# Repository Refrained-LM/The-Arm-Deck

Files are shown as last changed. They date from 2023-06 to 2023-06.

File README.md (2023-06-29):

# The-Arm-Deck
A customizable handheld device

First I would Like to name the users that have helped in either their model being used under Creative Commons (Give credit with a link), Stock, or modified to achieve this prototype.

EYEWINK 7" HDMI Display-C Case by ywabiko on Printables: https://www.printables.com/model/85018-eyewink-7-hdmi-display-c-case

Joycon Thumbstick by Keepinitril on Thingiverse: https://www.thingiverse.com/thing:5533819

Potentiometer trigger stackable by lynlim on Thingiverse: https://www.thingiverse.com/thing:1681562

Spring loaded linear converter Potentiometer  by Yoink_0b3 on Thingiverse: https://www.thingiverse.com/thing:2954927

Tactile Push Button(6x6x5mm) Switch Cap   by adimanav on Thingiverse: https://www.thingiverse.com/thing:4918184

Alan Chatham For the Arduino Uno/Mega Joy code that makes the controller possible. https://github.com/AlanChatham/UnoJoy

NicoHood For is Hood loader 2 system. I had to use his files to bring Arduino Uno back to stock as I am able to flash the serial controller directly. https://github.com/NicoHood/HoodLoader2
_________________________________________________________________________________________________________________________________

As of 6/5/23 This project could change drastically as this is the very beginning of publicly releasing this open-source design and community changes will be discussed and implemented.

____________________________________________________________________________________________________________________
List of current problems

1. Make internal stacked pressure-sensitive triggers with a stacked bumper design
2. Add ergonomics to the overall design.
3. Find a way to make a main power switch to shut the system down properly.
4. Make assembly instructions so other people can build without issues.

__________________________________________________________________________________________________________________

Currently In the works

1. Wiring Diagram
2. Parts List
3. Overall Design

_________________________________________________________________________________________________________________________
These Amazon links are regular links I am not an affiliate.

Parts List
1. [Single Board Computer with a Pico-ITX or standard RPI form factor. (I'm using a Radxa Rock 5B)](https://www.okdo.com/us/p/okdo-rock-5-model-b-8gb-single-board-computer-rockchip-rk3588-arm-cortex-a76-cortex-a55/)
2. [7 inch screen with screw holes on top and bottom, similar to the official Raspberry Pi 7" touchscreen display (linked)](https://www.amazon.com/Speakers-1024x600-Capacitive-Touchscreen-Raspberry/dp/B09L7XNBJB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) 
3. [Momentary push buttons](https://www.amazon.com/Twidec-Colors-Momentary-Pre-soldered-PBS-110-X6C/dp/B07RTZVZ6L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)
4. [Tactile buttons]( https://www.amazon.com/TWTADE-Yellow-Orange-6x6x5mm-Tactile/dp/B07C7211PJ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)
5. [Round Micro Push Button Switch On Off Mini Momentary Self-Locking Switch 2-Pin](https://www.amazon.com/TAODAN-Button-Switch-Momentary-Self-Locking/dp/B0BQ2Y9P2W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)
6. [Joycon Thumb sticks](https://www.amazon.com/Joycon-Joystick-Replacement-Controller-Thumbstick/dp/B08BL4LY84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)
7. [Heatsink](https://www.amazon.com/uxcell-Cross-Shaped-Notch-Heatsink/dp/B08HHZPYTF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) & [fans](https://www.amazon.com/dp/B08MKP8P3S/ref=twister_B09MSXKC88?_encoding=UTF8&psc=1)
8. [Rotary Potentiometer]( https://www.amazon.com/WGCD-Knurled-Linear-Rotary-Potentiometer/dp/B07B64MWRF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)
9. [M3 screw set]( https://www.amazon.com/VIGRUE-1110PCS-Stainless-Assortment-Tweezer/dp/B083SGJ7BD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)
10. [Right angle USB C to C 60 watt](https://www.amazon.com/3-Pack-Charge-Compatible-Samsung-MacBook/dp/B099N3VKCH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)
11. [Arduino Uno]( https://www.amazon.com/ELEGOO-Board-ATmega328P-ATMEGA16U2-Compliant/dp/B01EWOE0UU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)
12. [Wire (I'm currently using Dupont style wire)](https://www.amazon.com/SIM-NAT-Breadboard-Arduino-Raspberry/dp/B06XRV92ZB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)
13. [Battery pack]( https://www.amazon.com/gp/product/B0915T91JN/ref=ppx_yo_dt_b_search_asin_title?ie=UTF8&psc=1)
14. [USB A -> Micro B Ribbon cables](https://www.amazon.com/Micro-Ribbon-Degree-Standard-Charging/dp/B077RKFXJT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)
15. [Wireless (wifi, bluetooth) card, if required for your board](https://www.amazon.com/Wireless-Network-RTL8852BE-Universal-Bluetooth/dp/B0B5LQFGLG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)
16. [SSD, if supported by your board](https://www.amazon.com/SAMSUNG-Technology-Intelligent-Turbowrite-Sequential/dp/B08V7GT6F3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)
17. 3d Printer Filament I got PETG but PLA could be used but not advised for strength and heat resistance factor.
18. Springs will be needed for the triggers.....
19. [HDMI Male to Male 180 Degree angle](https://www.amazon.com/gp/product/B08FMKXN3D/ref=ppx_yo_dt_b_search_asin_title?ie=UTF8&psc=1)
20. [HDMI Male to Female FPC Flat](https://www.amazon.com/gp/product/B089Q9HMY5/ref=ppx_yo_dt_b_search_asin_title?ie=UTF8&psc=1)
21. [4layer brand Joy-Con Breakout board](https://4layertech.com/products/joystick-breakout-board-pack-of-2)
22. [USB A to C Cable That supports QC technology]()

These Amazon links are regular links I am not an affiliate.

***Note*** an Arduino Leonardo could be used in place of the Uno as the Arduino Leonardo/Micro has a specific library for game controllers, I do not have code for that currently but I will add it to the code base if someone beats me to it.
    The Arduino Joystick Library (a.k.a. Game Controller library) provides the following:

    X, Y, and Z axis
    32 buttons
    X, Y, and Z axis rotation
    Rudder
    Throttle
    2 Point of View Hat Switches

_____________________________________________________________________________________________________________________________________________________________

Overall design Current Cad workings







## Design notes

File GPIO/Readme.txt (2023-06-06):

This is for GPIO Related Addons such us custom keybinds to physical buttons on The Arm Deck

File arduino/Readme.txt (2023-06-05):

Use Megajoy-on-uno.ino and Megahoy.h in the Ardunio IDE and flash normally
Then reboot the device and put it in DFU mode and flash Megajoy.hex with dfu-programmer.
Reboot and it should show up as a game controller.

Put device in DFU mode and flash with Arduino-usbserial-uno.hex can be tricky I recommand another uno in ISP moden to reflash the bootloader in Ardunio IDE again can be tricky I added https://github.com/NicoHood/HoodLoader2 Files flash boot loader easier if needing to put the uno back to stock.

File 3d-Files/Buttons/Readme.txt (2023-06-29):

3d Files that contain button parts.

Shrink Monitor & GPIO buttons to %93 X and Y in cura.

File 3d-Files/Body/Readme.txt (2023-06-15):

Merged front panel body files to single model. Made a universal base for other boards so new slots could be cut out (Universal)

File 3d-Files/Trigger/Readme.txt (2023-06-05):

3d Files Containing Trigger system.
Modified From Spring loaded linear converter Potentiometer by Yoink_0b3 on Thingiverse: https://www.thingiverse.com/thing:2954927

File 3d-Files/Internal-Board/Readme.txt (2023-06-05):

3d Files containing Motheboard mounts and such

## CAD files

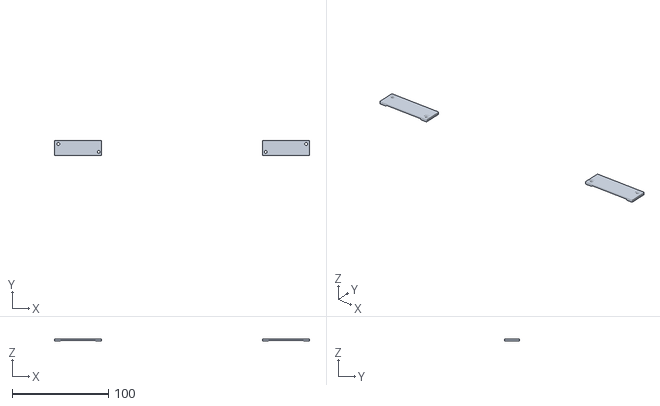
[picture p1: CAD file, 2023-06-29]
3d-Files/Body/Speaker Covers.stl
265.5 x 16.0 x 2.40

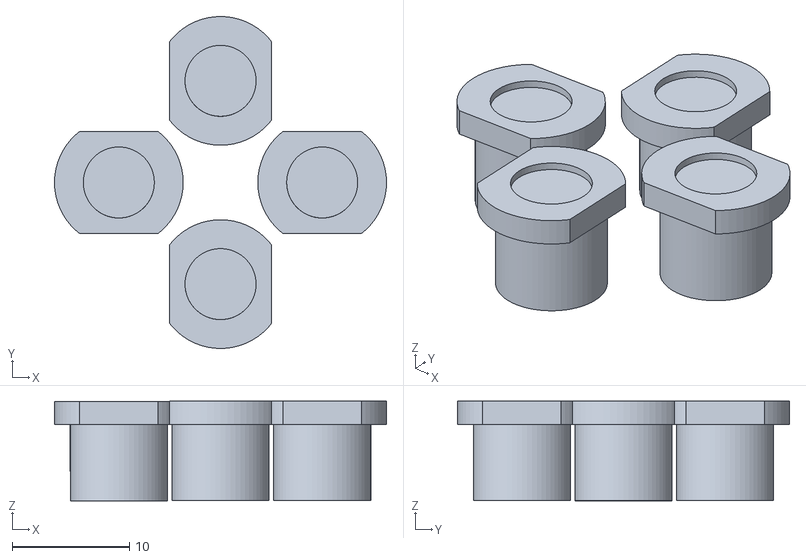
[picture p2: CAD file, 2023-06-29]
3d-Files/Buttons/ABXY Buttons.stl
28.4 x 28.4 x 8.51

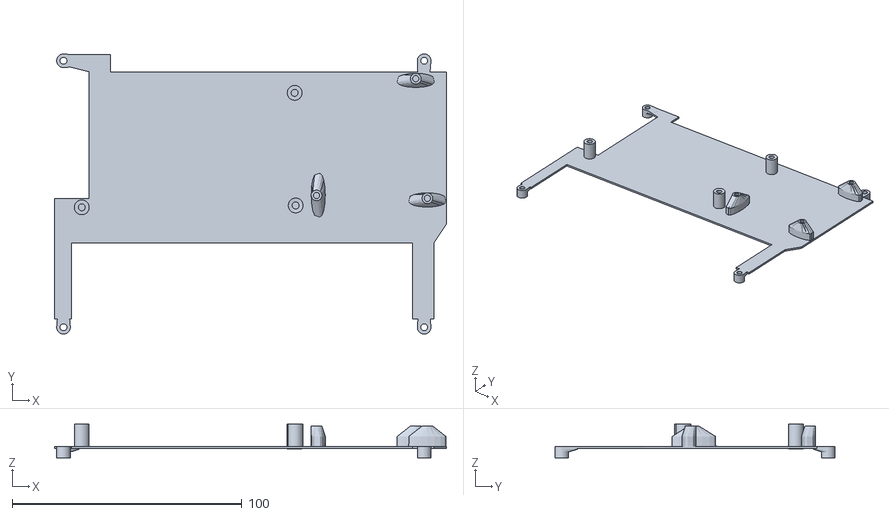
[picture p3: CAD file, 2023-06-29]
3d-Files/Internal-Board/Motherboard bracket 5B.stl
170.7 x 122.0 x 14.6

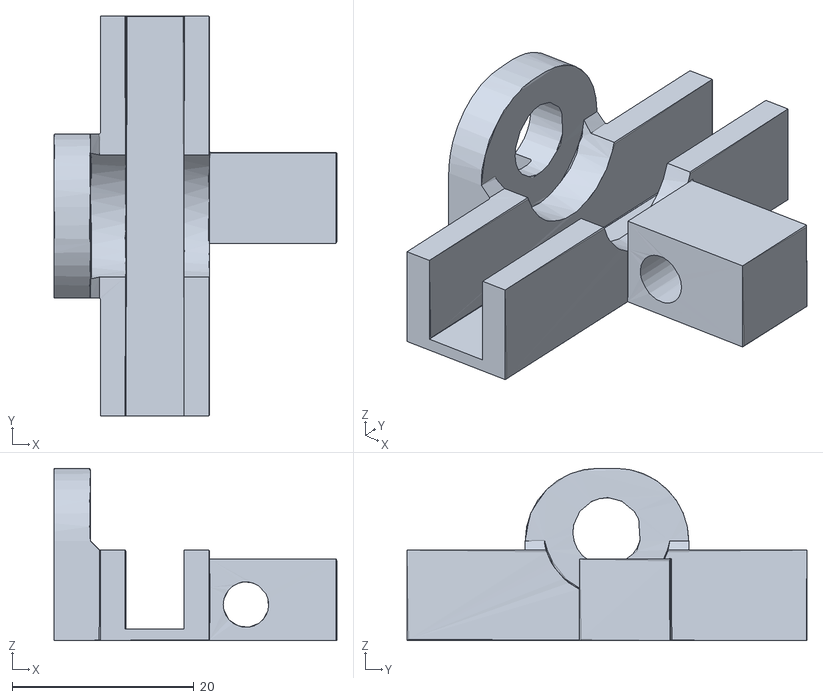
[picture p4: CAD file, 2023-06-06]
3d-Files/Trigger/Left Trigger Mount.stl
31.1 x 44.0 x 19.0

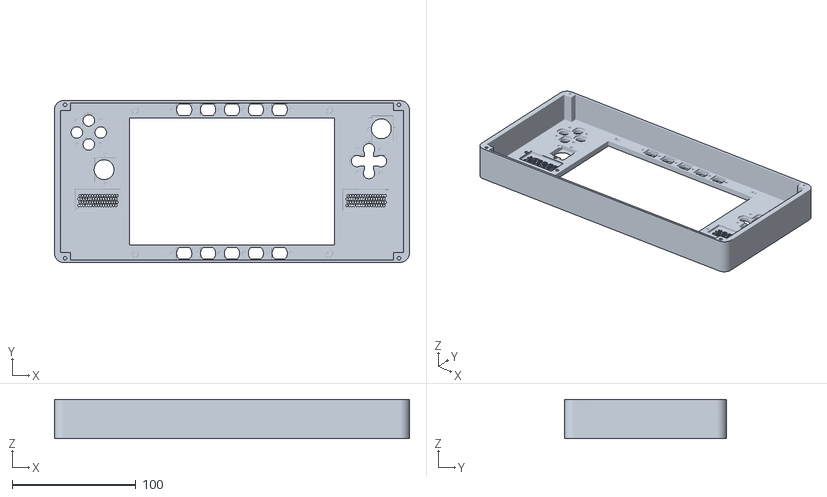
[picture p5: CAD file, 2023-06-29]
3d-Files/Body/Front Panel Universal.stl
287.0 x 131.0 x 31.6

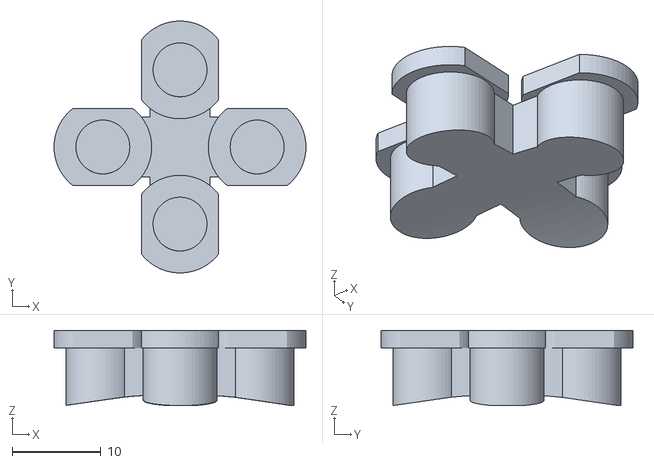
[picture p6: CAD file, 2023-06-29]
3d-Files/Buttons/Dpad Button.stl
28.4 x 28.4 x 8.50

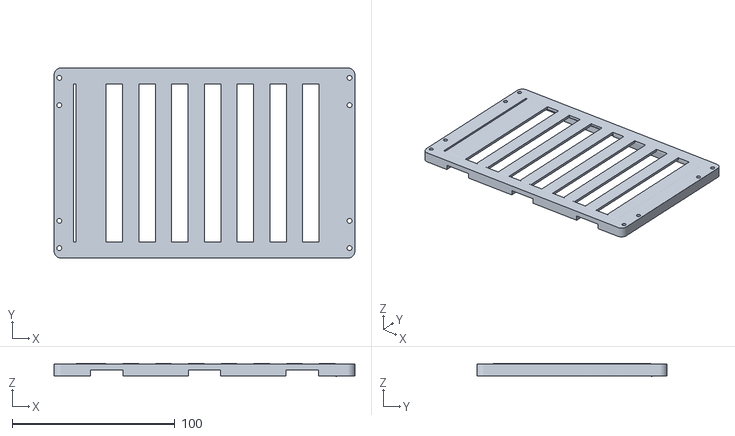
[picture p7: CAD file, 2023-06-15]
3d-Files/Body/Battery Panel with strap mounts.stl
184.9 x 117.0 x 7.73

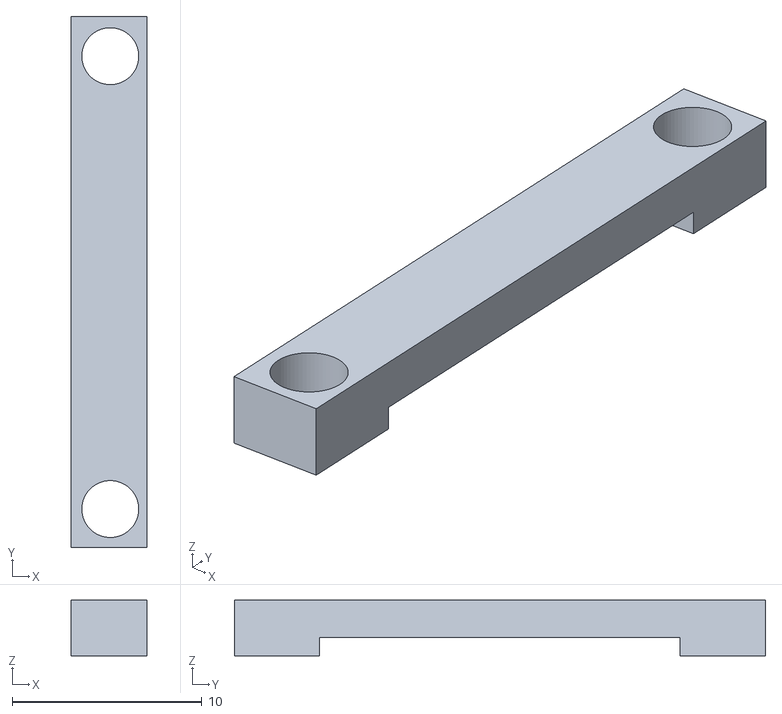
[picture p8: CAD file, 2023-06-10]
3d-Files/Buttons/ABXY Thumbstck Bracket.stl
4.00 x 28.0 x 2.94

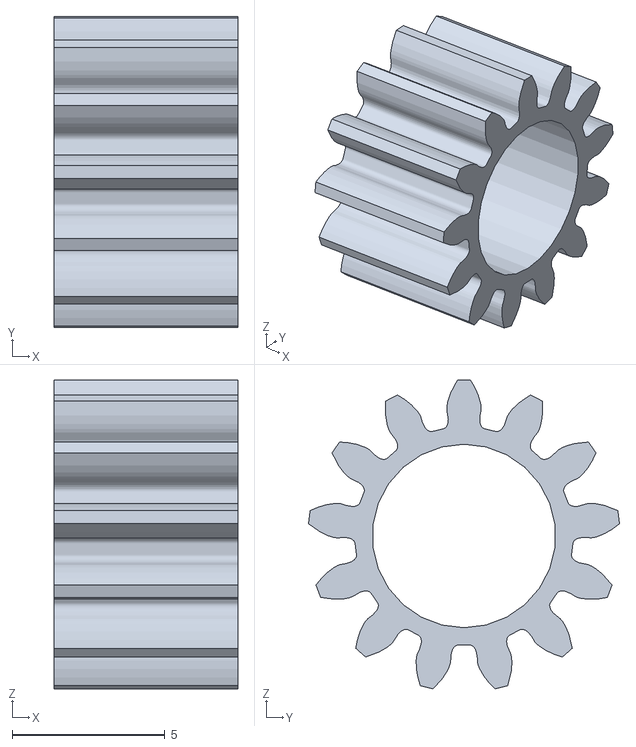
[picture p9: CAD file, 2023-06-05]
3d-Files/Trigger/Right Trigger Gear.stl
6.00 x 10.2 x 10.1

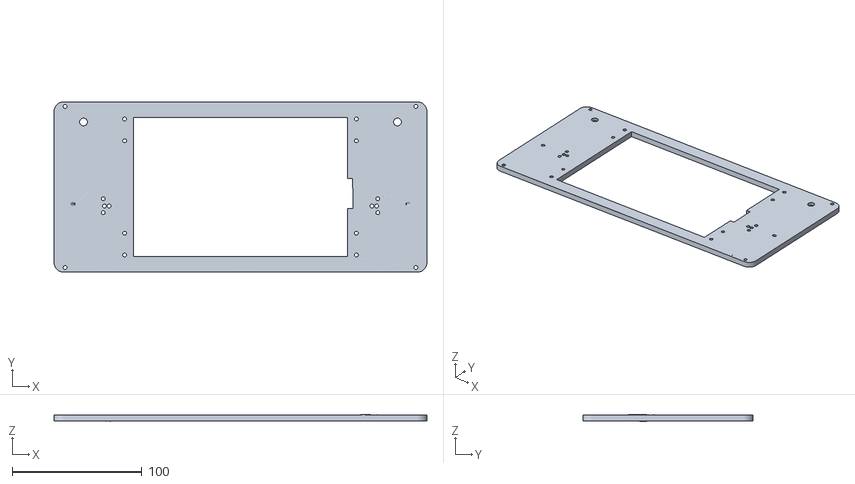
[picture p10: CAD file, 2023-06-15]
3d-Files/Body/Rear Panel.stl
287.0 x 131.0 x 5.00

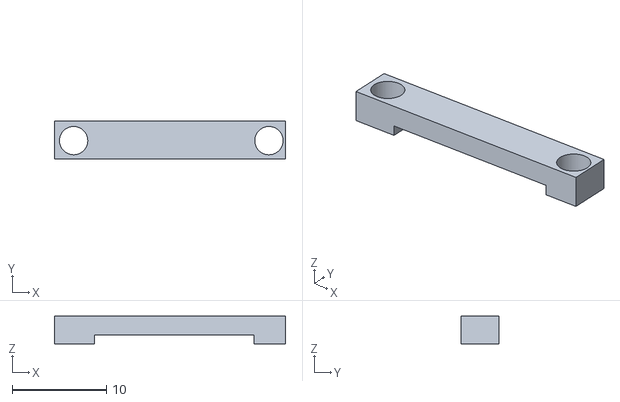
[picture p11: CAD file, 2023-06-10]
3d-Files/Buttons/Dpad Thumbstck Bracket.stl
24.5 x 4.00 x 2.94

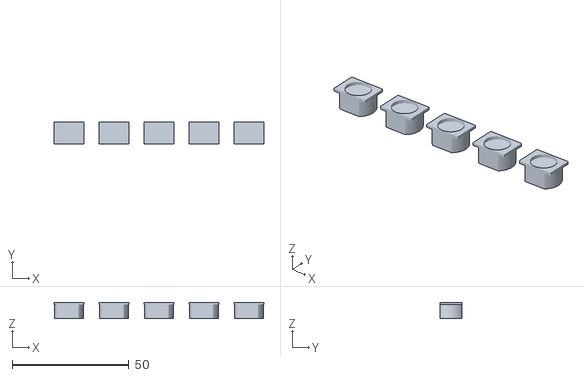
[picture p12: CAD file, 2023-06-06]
3d-Files/Buttons/GPIO Button.stl
90.1 x 9.44 x 7.00

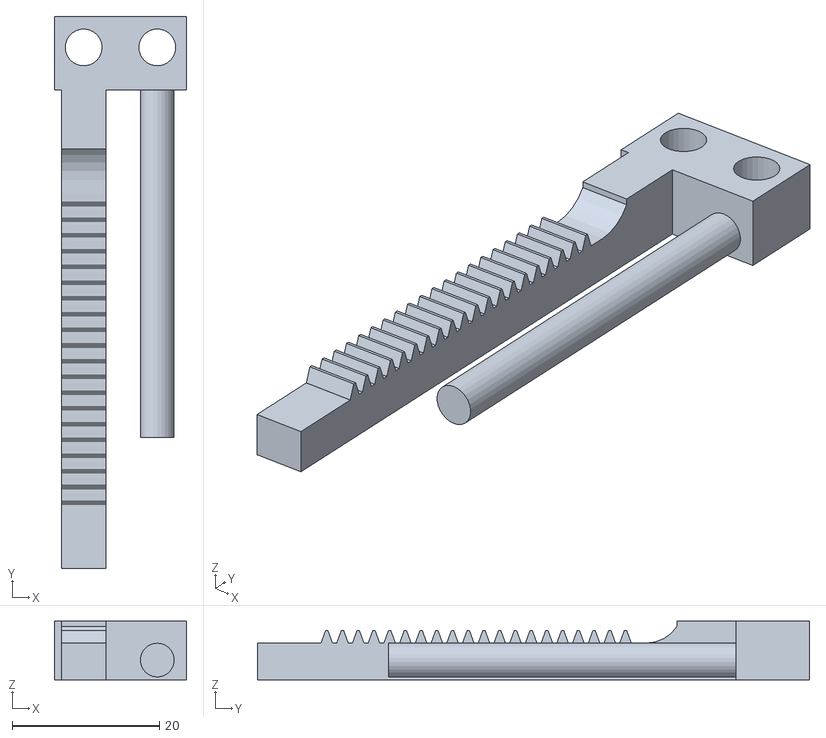
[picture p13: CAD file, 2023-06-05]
3d-Files/Trigger/Left Trigger Base.stl
18.0 x 75.0 x 8.00

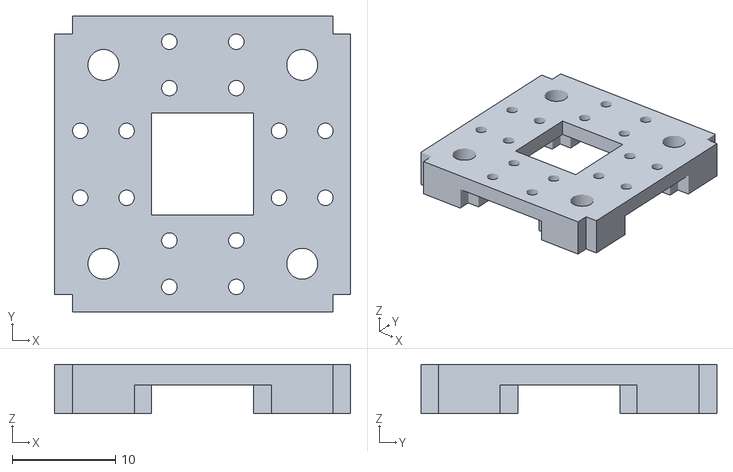
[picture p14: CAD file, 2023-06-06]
3d-Files/Buttons/Dpad Bracket.stl
28.7 x 28.7 x 4.80

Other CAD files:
3d-Files/Trigger/Right Trigger Mount.stl
3d-Files/Trigger/Left Trigger Gear.stl
3d-Files/Trigger/Right Trigger Base.stl
3d-Files/Buttons/GPIO Bracket.stl
3d-Files/Buttons/ABXY Bracket.stl
3d-Files/Buttons/Monitor Bracket.stl
3d-Files/Buttons/Monitor Buttons.stl

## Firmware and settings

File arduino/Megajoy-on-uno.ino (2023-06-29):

#include "MegaJoy.h"

void setup() {
  setupPins();
  setupMegaJoy();
}

void loop() {
  // Always be getting fresh data
  megaJoyControllerData_t controllerData = getControllerData();
  setControllerData(controllerData);
}

void setupPins(void) {
  // Set all the digital pins as inputs
  // with the pull-up enabled, except for the
  // two serial line pins
  for (int i = 2; i <= 15; i++) {
    pinMode(i, INPUT);
    digitalWrite(i, HIGH);
  }
}

megaJoyControllerData_t getControllerData(void) {

  // Set up a place for our controller data
  //  Use the getBlankDataForController() function, since
  //  just declaring a fresh dataForController_t tends
  //  to get you one filled with junk from other, random
  //  values that were in those memory locations before
  megaJoyControllerData_t controllerData = getBlankDataForMegaController();
  // Since our buttons are all held high and
  //  pulled low when pressed, we use the "!"
  //  operator to invert the readings from the pins
  for (int i = 2; i < 15; i++) {
    controllerData.buttonArray[(i - 2) / 8] |= (!digitalRead(i)) << ((i - 2) % 8);
  }

  // Set the analog sticks
  //  Since analogRead(pin) returns a 10 bit value,
  //  we need to perform a bit shift operation to
  //  lose the 2 least significant bits and get an
  //  8 bit number that we can use
  controllerData.analogAxisArray[0] = analogRead(A0); >> 2;
  controllerData.analogAxisArray[1] = analogRead(A1); >> 2;
  controllerData.analogAxisArray[2] = analogRead(A2); >> 2;
  controllerData.analogAxisArray[3] = analogRead(A3); >> 2;
  controllerData.analogAxisArray[4] = analogRead(A4); >> 2;
  controllerData.analogAxisArray[5] = analogRead(A5); >> 2;
  
  // And return the data!
  return controllerData;

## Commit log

2023-06-05 Create Megajoy-on-uno.ino
    The file that gets written on Arduino uno via the normal process.
2023-06-15 Delete 3d-Files/Battery-Back directory
    Deleting 1.0 to make way for 1.1
    [Battery Base.stl, Battery cover.stl, Main Power N Screen Power Holding Brackets.stl]
2023-06-15 Delete 3d-Files/Body directory
    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
    [Front Panel.stl, Left Vent.stl, Modified 10mm Spacer.stl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]
2023-06-15 Add files via upload
    Updated Body Panels to Version 1.1. Merged Front Panel into one piece and made a "Universal base" for other boards
    [Battery Panel with strap mounts.stl, Front Panel 5B.stl, Front Panel Universal.stl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]
2023-06-15 Delete Motherboard and arduino bracket.stl
    Making room for Version 1.1 Files
    [Motherboard and arduino bracket.stl]
2023-06-15 Add files via upload
    Updated to Version 1.1
    [Motherboard and arduino bracket.stl]
2023-06-29 Update Megajoy-on-uno.ino
    Updated Analog array from 10bit to 8 bit to account for jitter.
    [Megajoy-on-uno.ino]
2023-06-29 Add files via upload
    Updated SIze
    [ABXY Buttons.stl, Dpad Button.stl]
2023-06-29 Add files via upload
    Added speaker covers so Joycon breakout board can be attached.
    [Front Panel Universal.stl, Speaker Covers.stl]
2023-06-29 Add files via upload
    Switched Arduino and motherboard positions, added 3rd standoff for Arduino, and moved motherboard legs around.
    [Motherboard bracket 5B.stl]
